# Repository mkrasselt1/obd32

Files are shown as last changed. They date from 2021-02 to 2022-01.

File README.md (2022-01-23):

# obd32
The goal of this project is to create a esp32 based pcb and software to
catch and submit automotive data from obd2 ports of supported vehicles 
to a given (list of ) endpoints(s). 

Anyone is free to join our goal to make the hardware reliable and affordable.

current plan conatins the featureset of:

    - esp32 based microprocessor
    - direct canbus via tranciever chip MCP2562-e
    - db9 for obd2 connection
    - wifi connection to hotsport or
    - onboard switchable usb port for lte-wifi-router 
    - ~~bluetooth connection compatible with elm327ds~~
    - micro sd card slot for configuration, logging and cache
    - ota updates via github releases
    - build in webfrontend
    - low power sleep mode (canbus activity and battery voltage)
    - gps for location and altitude sync
    - communication protocolls: https-post, websocket, mqtt

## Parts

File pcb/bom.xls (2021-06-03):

Comment | Designator | Quantity | Footprint | Datasheet
4K7 | R1, R2 | 2 | R_0603_1608Metric | ~
10K | R3, R23, R24 | 3 | R_0402_1005Metric | ~
64.9R | R4, R5 | 2 | R_0402_1005Metric | ~
4.99R | R6 | 1 | R_0402_1005Metric | ~
22.1K | R7 | 1 | R_0402_1005Metric | ~
47.5K | R8 | 1 | R_0402_1005Metric | ~
1K | R9 | 1 | R_0402_1005Metric | ~
100K | R10, R21 | 2 | R_0402_1005Metric | ~
27K | R11 | 1 | R_0402_1005Metric | ~
200K | R12 | 1 | R_0402_1005Metric | ~
22K | R13 | 1 | R_0402_1005Metric | ~
5.1K | R14, R15 | 2 | R_0402_1005Metric | ~
27R | R16, R19 | 2 | R_0402_1005Metric | ~
120R | R17 | 1 | R_0402_1005Metric | ~
10R | R18 | 1 | R_0402_1005Metric | ~
24.9K | R22 | 1 | R_0402_1005Metric | ~
100nF | C1, C3 | 2 | C_0805_2012Metric | ~
1uF | C2, C10 | 2 | C_0402_1005Metric | ~
10uF | C4, C6 | 2 | C_0805_2012Metric | ~
22uF | C5, C12, C13, C25 | 4 | C_0805_2012Metric | ~
10uF 20V | C7 | 1 | C_0805_2012Metric | ~
220nF 20V | C8 | 1 | C_0402_1005Metric | ~
0.1uF | C9, C11, C16, C18, C19, C20, C21 | 7 | C_0402_1005Metric | ~
10nF | C14 | 1 | C_0402_1005Metric | ~
0.47uF | C15 | 1 | C_0402_1005Metric | ~
100nF | C17, C22 | 2 | C_0402_1005Metric | ~
LED | D1 | 1 | LED_0402_1005Metric red | ~
LED | D2 | 1 | LED_0402_1005Metric green | ~
LED | D3 | 1 | LED_0402_1005Metric blue | ~
SM6T18A | D4 | 1 | D_SMB | https://www.digikey.com/en/products/detail/stmicroelectronics/SM6T18A/1039077
D_Schottky | D5, D8 | 2 | D_SMA | https://www.digikey.com/en/products/detail/vishay-general-semiconductor-diodes-division/SSB43L-M3-5BT/4872661
SP0503BAHT | D6 | 1 | SOT-143 | https://www.digikey.com/en/products/detail/littelfuse-inc/SP0503BAHT/485122
D_Zener | D7 | 1 | D_0201_0603Metric | https://www.digikey.com/en/products/detail/diodes-incorporated/GDZ6V0LP3-7/3075699
Polyfuse | F1 | 1 | Fuse_1812_4532Metric | https://www.digikey.com/en/products/detail/littelfuse-inc/1812L150-16DR/3305611
67329-8040 | J1 | 1 | Molex 67329-8040 | https://www.digikey.com/en/products/detail/molex/0673298040/13572467
USB_C_Receptacle_USB2.0 | J2 | 1 | USB_C_Receptacle JAE DX07S016JA1 | https://www.digikey.com/en/products/detail/jae-electronics/DX07S016JA1R1500/11585731
Micro_SD_Card | J6 | 1 | microSD_HC_Hirose_DM3AT-SF-PEJM5 | https://www.digikey.com/en/products/detail/hirose-electric-co-ltd/DM3AT-SF-PEJM5/2533565
U.FL-R-SMT-101 | J7 | 1 | U.FL-R-SMT-101 | https://www.digikey.com/en/products/detail/hirose-electric-co-ltd/U-FL-R-SMT-1-01/3978494
3.3uH 4A 16mR | L2 | 1 | TDK_SPM5030 | https://www.digikey.com/en/products/detail/tdk-corporation/SPM5030T-3R3M/9555054
BC817 | Q1, Q2 | 2 | Generic BC817 SOT-23
SW_Push | SW1, SW2, SW3 | 3 | Switch B3U-3000P-B | https://www.digikey.com/en/products/detail/omron-electronics-inc-emc-div/B3U-3000P-B/1811779
FTDI FT231XQ | U1 | 1 | FT231XQ QFN20 | https://www.digikey.com/en/products/detail/ftdi-future-technology-devices-international-ltd/FT231XQ-T/3749470
ESP32-WROOM-32 | U2 | 1 | ESP32-WROOM-32U (16MB) | https://www.digikey.com/en/products/detail/espressif-systems/ESP32-WROOM-32U-16MB/9381721
AZ1117C-3.3 | U3 | 1 | AZ1117R-3.3TRE1 | https://www.digikey.com/en/products/detail/diodes-incorporated/AZ1117R-3-3TRE1/5306009
LMR33640DDDA | U4 | 1 | LMR33640DDDAR | https://www.digikey.com/en/products/detail/texas-instruments/LMR33640DDDAR/11308833
MCP2562FD-E-MF or MCP2562FD-H-MF | U7 | 1 | Package_DFN_QFN:DFN-8-1EP_3x3mm_P0.65mm_EP1.55x2.4mm | https://www.digikey.com/en/products/detail/microchip-technology/MCP2562FD-E-MF/4842806
SiP32431DR3 | U8 | 1 | Package_TO_SOT_SMD:SOT-363_SC-70-6 | https://www.digikey.com/en/products/detail/vishay-siliconix/SIP32431DR3-T1GE3/2643559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
v Below may be left unpopulated if not available v
Ublox MAX-M8W | U9 | 1 | RF_GPS:ublox_MAX | https://www.digikey.com/en/products/detail/u-blox/MAX-M8W-0/6150637
ICM-20689 | U5 | 1 | ICM-20689 | https://www.digikey.com/en/products/detail/tdk-invensense/ICM-20689/5872869
BMP388 | U6 | 1 | BMP388 | https://www.digikey.com/en/products/detail/bosch-sensortec/BMP388/8322638

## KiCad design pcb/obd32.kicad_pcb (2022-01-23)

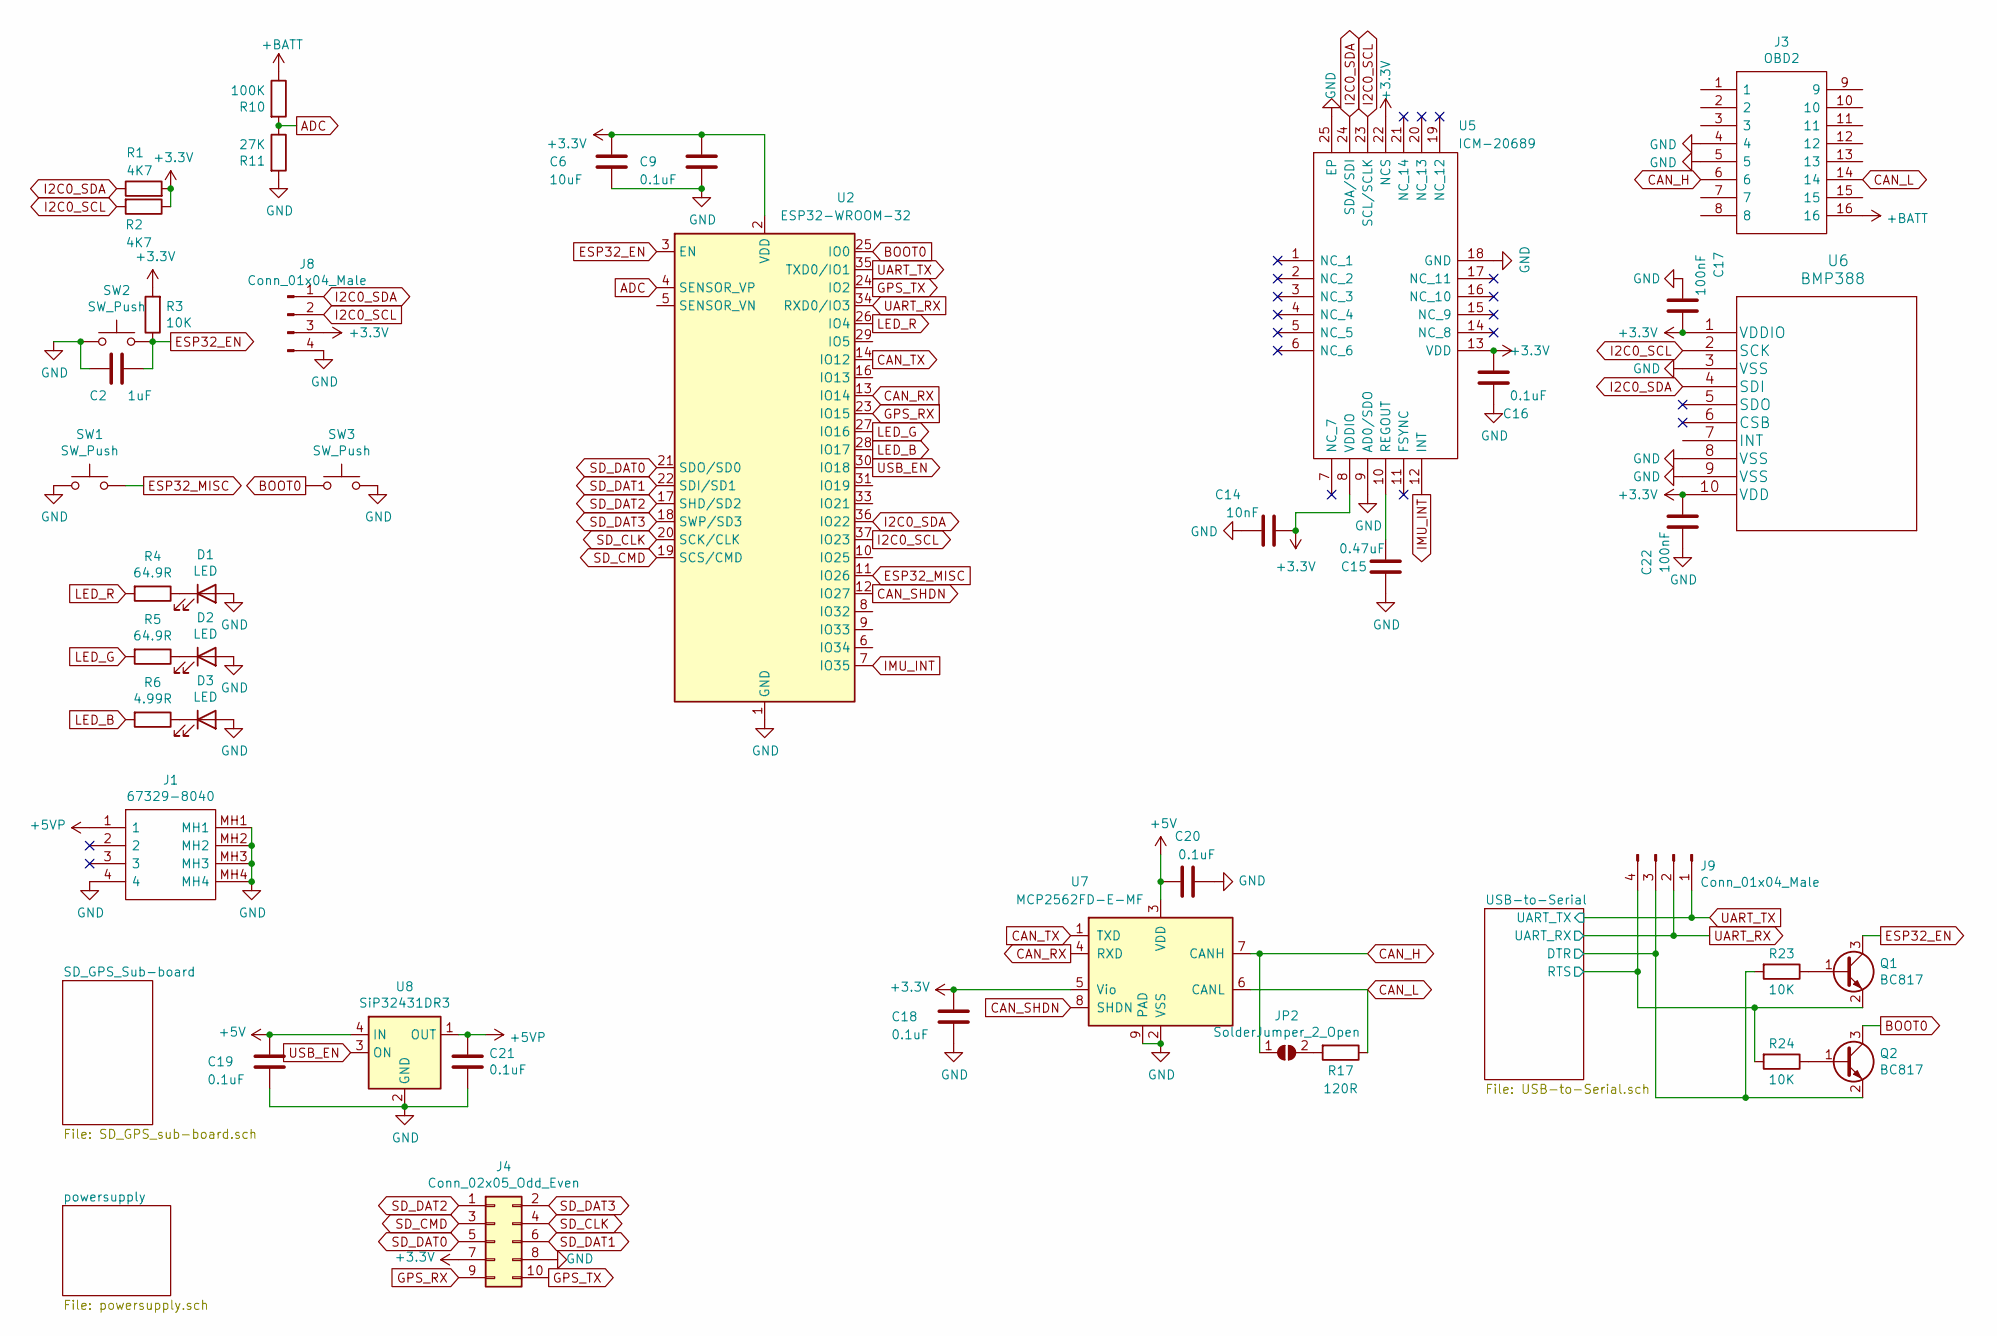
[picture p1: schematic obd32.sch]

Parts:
C2: 1uF; C_0402_1005Metric
C6: 10uF; C_0805_2012Metric
C9, C16, C18, C19, C20, C21: 0.1uF; C_0402_1005Metric
C14: 10nF; C_0402_1005Metric
C15: 0.47uF; C_0402_1005Metric
C17, C22: 100nF; C_0402_1005Metric
D1, D2, D3: LED; LED_0402_1005Metric
J1: 67329-8040; 673298040; Manufacturer_Part_Number 67329-8040; Mouser Part Number 538-67329-8040
J3: OBD2; Manufacturer_Part_Number OBD2
J4: Conn_02x05_Odd_Even; PinSocket_2x05_P2.54mm_Vertical
J8, J9: Conn_01x04_Male; PinHeader_1x04_P2.54mm_Vertical
JP2: SolderJumper_2_Open; SolderJumper-2_P1.3mm_Open_RoundedPad1.0x1.5mm
Q1, Q2: BC817; SOT-23
R1, R2: 4K7; R_0603_1608Metric
R3, R23, R24: 10K; R_0402_1005Metric
R4, R5: 64.9R; R_0402_1005Metric
R6: 4.99R; R_0402_1005Metric
R10: 100K; R_0402_1005Metric
R11: 27K; R_0402_1005Metric
R17: 120R; R_0402_1005Metric
SW1, SW2, SW3: SW_Push; SW_SPST_B3U-3000P-B
U2: ESP32-WROOM-32; ESP32-WROOM-32U
U5: ICM-20689; QFN50P400X400X95-25N-D; Manufacturer_Part_Number ICM-20689; Mouser Part Number 410-ICM-20689
U6: BMP388
U7: MCP2562FD-E-MF; DFN-8-1EP_3x3mm_P0.65mm_EP1.55x2.4mm
U8: SiP32431DR3; SOT-363_SC-70-6

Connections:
+3V3: C6.1, C9.1, C14.2, C16.2, C17.2, C18.2, C22.2, J4.7, J8.3, R1.2, R2.1, R3.2, U2.2 (VDD), U5.8 (VDDIO), U5.13 (VDD), U5.22 (NCS), U6.1 (VDDIO), U6.10 (VDD), U7.5 (Vio); also elsewhere on the board
+5V: C19.1, C20.1, U7.3 (VDD), U8.4 (IN); also elsewhere on the board
+5VP: C21.1, J1.1, U8.1 (OUT)
+BATT: J3.16, R10.1; also elsewhere on the board
/USB-to-Serial/DTR: J9.3, Q2.2 (E), R23.2; also elsewhere on the board
/USB-to-Serial/RTS: J9.4, Q1.2 (E), R24.2; also elsewhere on the board
ADC: R10.2, R11.1, U2.4 (SENSOR_VP)
BOOT0: Q2.3 (C), SW3.1, U2.25 (IO0)
CAN_H: J3.6, JP2.1 (A), U7.7 (CANH)
CAN_L: J3.14, R17.1, U7.6 (CANL)
CAN_RX: U2.13 (IO14), U7.4 (RXD)
CAN_SHDN: U2.12 (IO27), U7.8 (SHDN)
CAN_TX: U2.14 (IO12), U7.1 (TXD)
ESP32_EN: C2.2, Q1.3 (C), R3.1, SW2.2, U2.3 (EN)
ESP32_MISC: SW1.2, U2.11 (IO26)
GND: C2.1, C6.2, C9.2, C14.1, C15.1, C16.1, C17.1, C18.1, C19.2, C20.2, C21.2, C22.1, D1.2 (A), D2.2 (A), D3.2 (A), J1.4, J1.MH1, J1.MH2, J1.MH3, J1.MH4, J3.4, J3.5, J4.8, J8.4, R11.2, SW1.1, SW2.1, SW3.2, U2.1 (GND), U2.15 (GND), U2.38 (GND), U2.39 (GND), U5.9 (AD0/SDO), U5.18 (GND), U5.25 (EP), U6.3 (VSS), U6.8 (VSS), U6.9 (VSS), U7.2 (VSS), U7.9 (PAD), U8.2 (GND), U8.5 (GND); also elsewhere on the board
GPS_RX: J4.9, U2.23 (IO15)
GPS_TX: J4.10, U2.24 (IO2)
I2C0_SCL: J8.2, R2.2, U2.37 (IO23), U5.23 (SCL/SCLK), U6.2 (SCK)
I2C0_SDA: J8.1, R1.1, U2.36 (IO22), U5.24 (SDA/SDI), U6.4 (SDI)
IMU_INT: U2.7 (IO35), U5.12 (INT)
LED_B: R6.2, U2.28 (IO17)
LED_G: R5.2, U2.27 (IO16)
LED_R: R4.2, U2.26 (IO4)
unnamed: C15.2, U5.10 (REGOUT)
unnamed: D1.1 (K), R4.1
unnamed: D2.1 (K), R5.1
unnamed: D3.1 (K), R6.1
unnamed: JP2.2 (B), R17.2
unnamed: Q1.1 (B), R23.1
unnamed: Q2.1 (B), R24.1
SD_CLK: J4.4, U2.20 (SCK/CLK)
SD_CMD: J4.3, U2.19 (SCS/CMD)
SD_DAT0: J4.5, U2.21 (SDO/SD0)
SD_DAT1: J4.6, U2.22 (SDI/SD1)
SD_DAT2: J4.1, U2.17 (SHD/SD2)
SD_DAT3: J4.2, U2.18 (SWP/SD3)
UART_RX: J9.2, U2.34 (RXD0/IO3); also elsewhere on the board
UART_TX: J9.1, U2.35 (TXD0/IO1); also elsewhere on the board
USB_EN: U2.30 (IO18), U8.3 (ON)

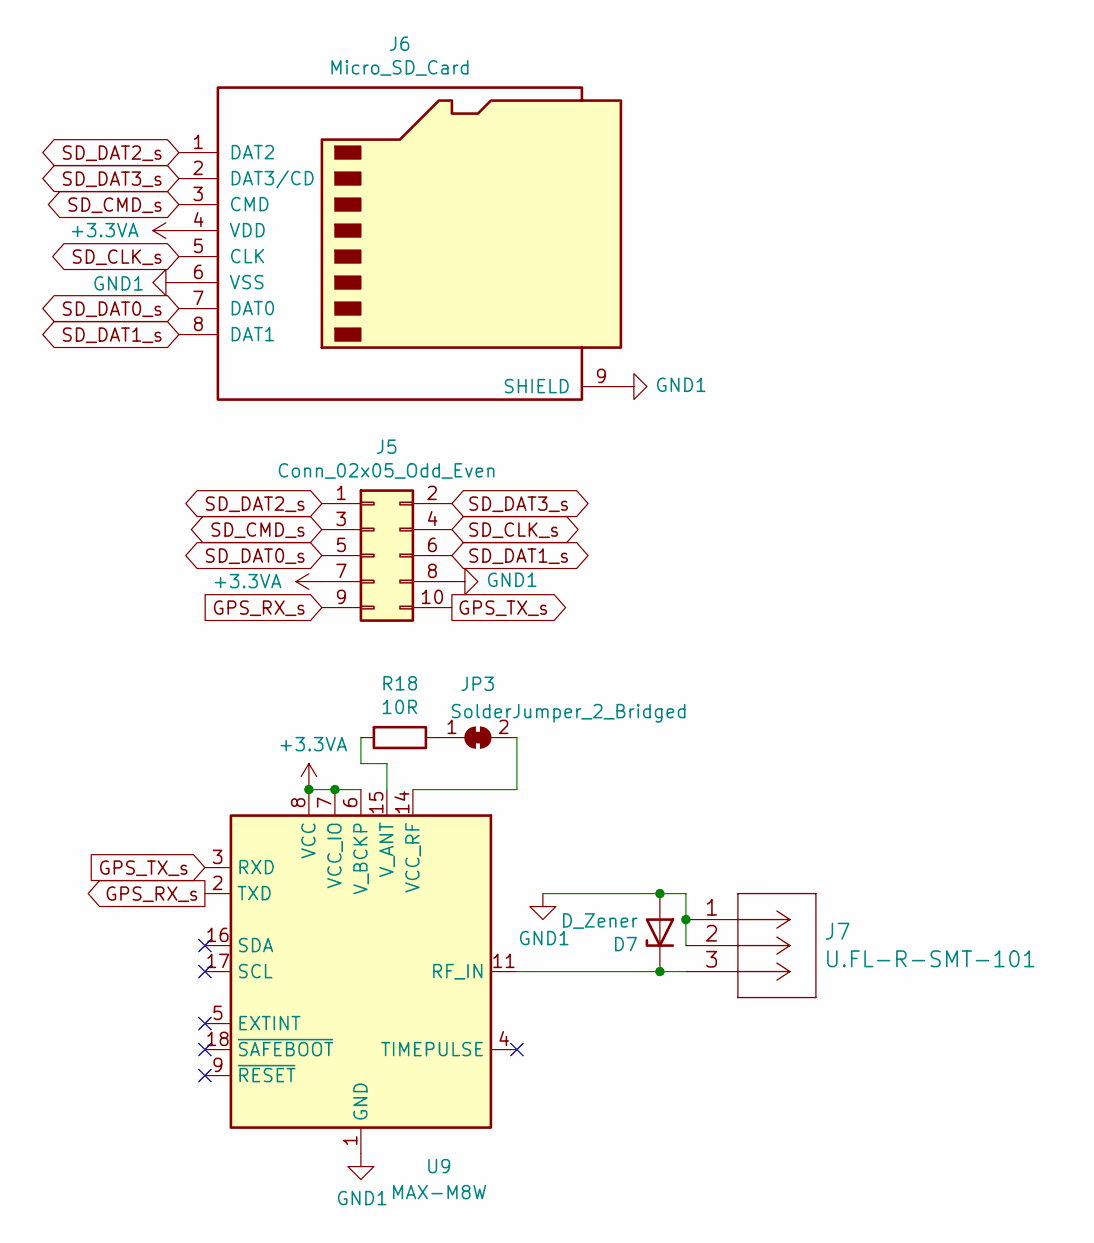
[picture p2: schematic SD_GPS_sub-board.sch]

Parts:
D7: D_Zener; D_0201_0603Metric
J5: Conn_02x05_Odd_Even; PinHeader_2x05_P2.54mm_Vertical
J6: Micro_SD_Card; microSD_HC_Hirose_DM3AT-SF-PEJM5
J7: U.FL-R-SMT-101
JP3: SolderJumper_2_Bridged; SolderJumper-2_P1.3mm_Bridged_RoundedPad1.0x1.5mm
R18: 10R; R_0402_1005Metric
U9: MAX-M8W; ublox_MAX

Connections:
+3.3VA: J5.7, J6.4 (VDD), U9.6 (V_BCKP), U9.7 (VCC_IO), U9.8 (VCC)
GND1: D7.2 (A), J5.8, J6.6 (VSS), J6.9 (SHIELD), J7.1 (GND), J7.2 (GND), U9.1 (GND), U9.10 (GND), U9.12 (GND)
GPS_RX_s: J5.9, U9.2 (TXD)
GPS_TX_s: J5.10, U9.3 (RXD)
unnamed: D7.1 (K), J7.3 (SIG), U9.11 (RF_IN)
unnamed: JP3.1 (A), R18.1
unnamed: JP3.2 (B), U9.14 (VCC_RF)
unnamed: R18.2, U9.15 (V_ANT)
SD_CLK_s: J5.4, J6.5 (CLK)
SD_CMD_s: J5.3, J6.3 (CMD)
SD_DAT0_s: J5.5, J6.7 (DAT0)
SD_DAT1_s: J5.6, J6.8 (DAT1)
SD_DAT2_s: J5.1, J6.1 (DAT2)
SD_DAT3_s: J5.2, J6.2 (DAT3/CD)

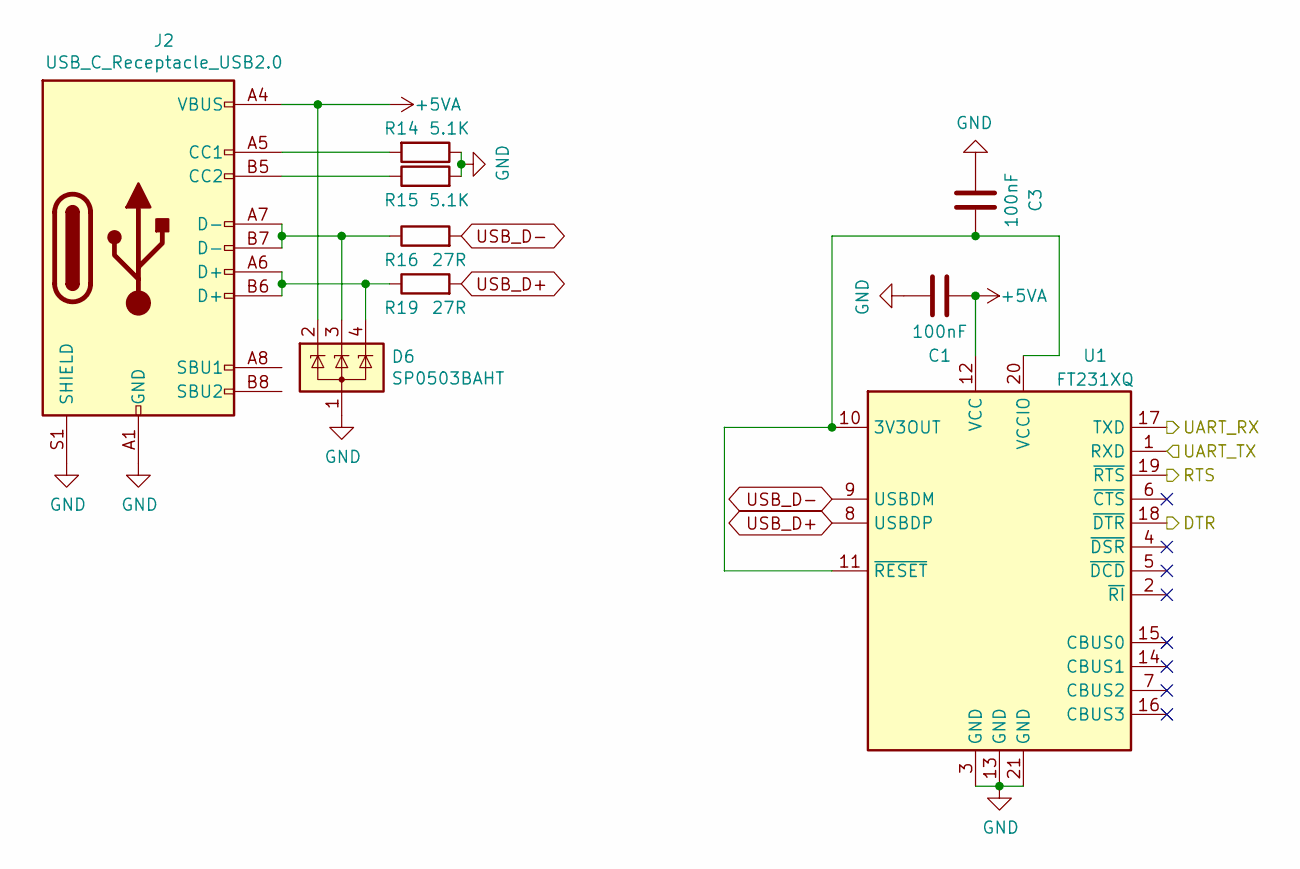
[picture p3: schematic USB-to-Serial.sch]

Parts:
C1, C3: 100nF; C_0805_2012Metric
D6: SP0503BAHT; SOT-143
J2: USB_C_Receptacle_USB2.0; USB_C_Receptacle_JAE_DX07S016JA1
R14, R15: 5.1K; R_0402_1005Metric
R16, R19: 27R; R_0402_1005Metric
U1: FT231XQ; QFN-20-1EP_4x4mm_P0.5mm_EP2.5x2.5mm

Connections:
+5VA: C1.2, D6.2 (K), J2.A4 (VBUS), J2.A9 (VBUS), J2.B4 (VBUS), J2.B9 (VBUS), U1.12 (VCC); also elsewhere on the board
/USB-to-Serial/DTR: U1.18 (~DTR); also elsewhere on the board
/USB-to-Serial/RTS: U1.19 (~RTS); also elsewhere on the board
GND: C1.1, C3.2, D6.1 (A), J2.A1 (GND), J2.A12 (GND), J2.B1 (GND), J2.B12 (GND), J2.S1 (SHIELD), R14.1, R15.2, U1.3 (GND), U1.13 (GND), U1.21 (GND); also elsewhere on the board
unnamed: C3.1, U1.10 (3V3OUT), U1.11 (~RESET), U1.20 (VCCIO)
unnamed: D6.3 (K), J2.A7 (D-), J2.B7 (D-), R16.1
unnamed: D6.4 (K), J2.A6 (D+), J2.B6 (D+), R19.1
unnamed: J2.A5 (CC1), R14.2
unnamed: J2.B5 (CC2), R15.1
UART_RX: U1.17 (TXD); also elsewhere on the board
UART_TX: U1.1 (RXD); also elsewhere on the board
USB_D+: R19.2, U1.8 (USBDP)
USB_D-: R16.2, U1.9 (USBDM)

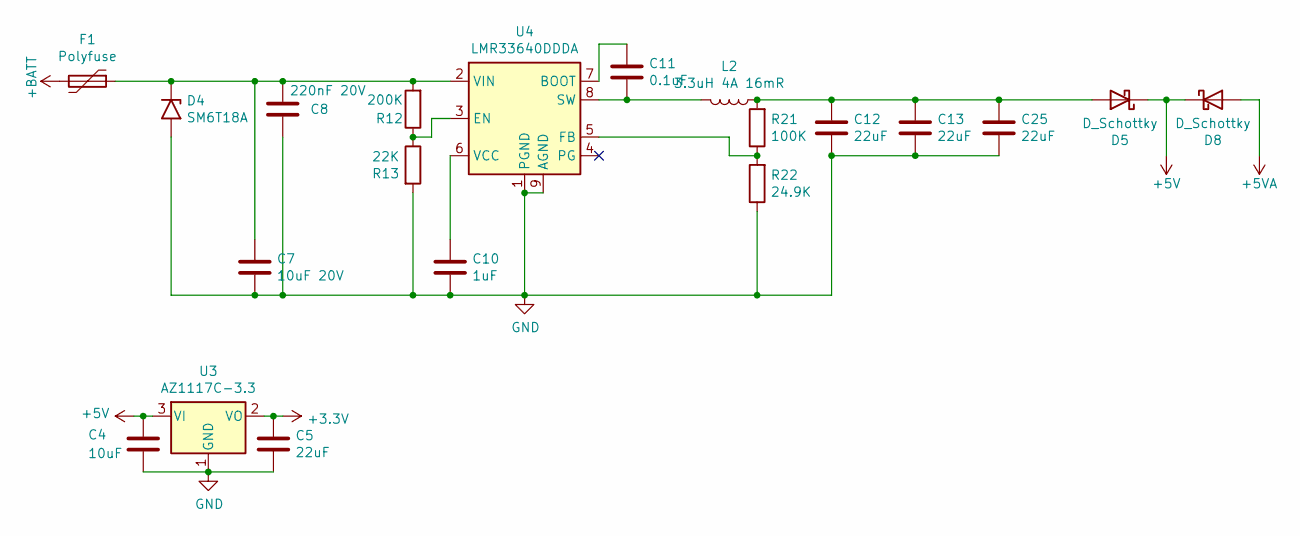
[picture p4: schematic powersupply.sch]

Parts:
C4: 10uF; C_0805_2012Metric
C5, C12, C13, C25: 22uF; C_0805_2012Metric
C7: 10uF 20V; C_0805_2012Metric
C8: 220nF 20V; C_0402_1005Metric
C10: 1uF; C_0402_1005Metric
C11: 0.1uF; C_0402_1005Metric
D4: SM6T18A; D_SMB
D5, D8: D_Schottky; D_SMA
F1: Polyfuse; Fuse_1812_4532Metric_Castellated
L2: 3.3uH 4A 16mR; TDK_SPM5030
R12: 200K; R_0402_1005Metric
R13: 22K; R_0402_1005Metric
R21: 100K; R_0402_1005Metric
R22: 24.9K; R_0402_1005Metric
U3: AZ1117C-3.3; SOT-89-3
U4: LMR33640DDDA; Texas_HSOP-8-1EP_3.9x4.9mm_P1.27mm_ThermalVias

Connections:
+3V3: C5.1, U3.2 (VO); also elsewhere on the board
+5V: C4.1, D5.1 (K), D8.1 (K), U3.3 (VI); also elsewhere on the board
+5VA: D8.2 (A); also elsewhere on the board
+BATT: F1.2; also elsewhere on the board
GND: C4.2, C5.2, C7.2, C8.2, C10.2, C12.2, C13.2, C25.2, D4.2 (A2), R13.2, R22.1, U3.1 (GND), U4.1 (PGND), U4.9 (AGND); also elsewhere on the board
unnamed: C7.1, C8.1, D4.1 (A1), F1.1, R12.2, U4.2 (VIN)
unnamed: C10.1, U4.6 (VCC)
unnamed: C11.1, U4.7 (BOOT)
unnamed: C11.2, L2.2, U4.8 (SW)
unnamed: C12.1, C13.1, C25.1, D5.2 (A), L2.1, R21.2
unnamed: R12.1, R13.1, U4.3 (EN)
unnamed: R21.1, R22.2, U4.5 (FB)

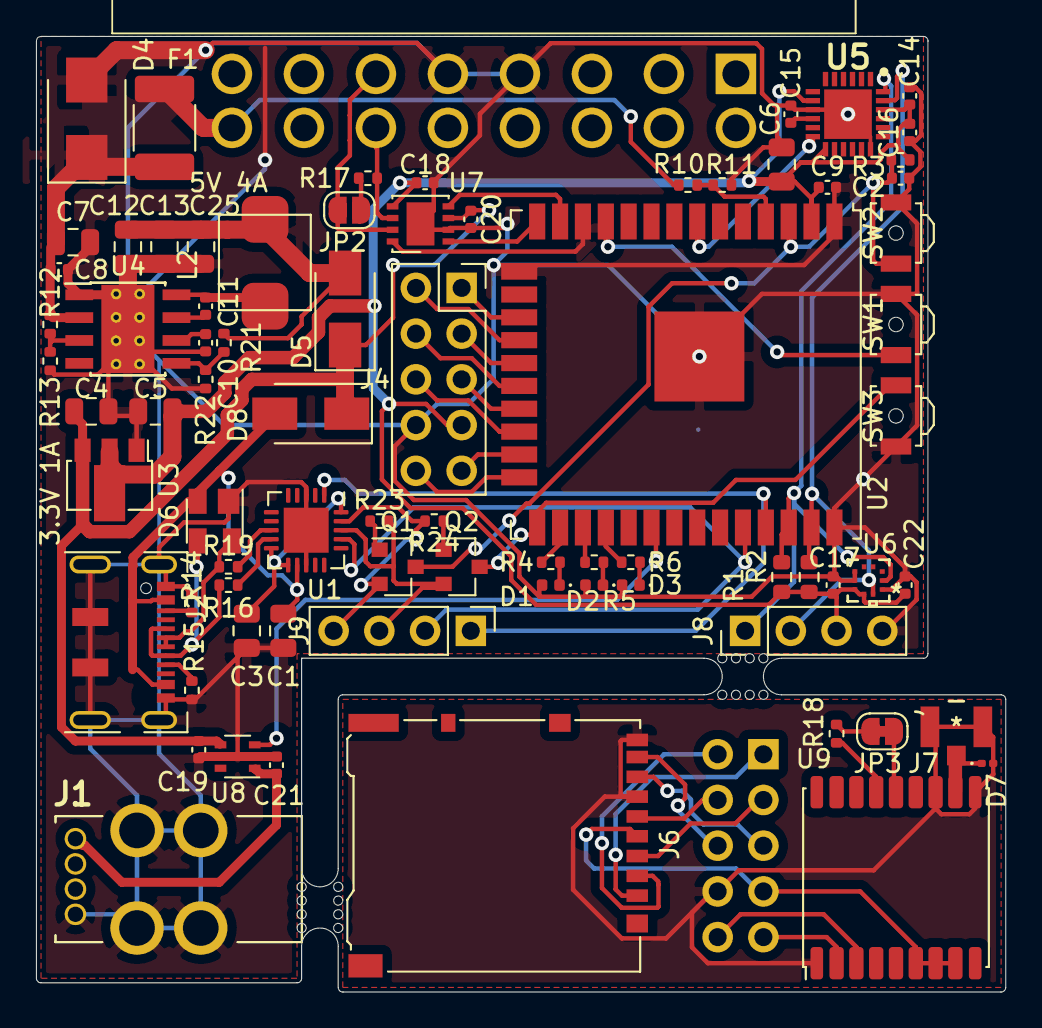
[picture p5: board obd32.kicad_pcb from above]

Board: 2 copper layers, 53.8 x 53.1 mm, 78 parts (1 on the bottom side), 69 nets.

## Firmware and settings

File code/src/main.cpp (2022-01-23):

#include <Arduino.h>
#include <Update.h>
#include "FS.h"
#include "SPIFFS.h"
#include "Wifi.h"
#include <WiFiClient.h>
#include <ESPmDNS.h>
#include <AsyncTCP.h>
#include <ESPAsyncWebServer.h>
#include "pins.h"

const char *sta_ssid = "obd32";
const char *sta_password = "obd32";
const char *host = "obd32";

unsigned long previousMillis = 0; // will store last time LED was updated
const long interval = 150;        // interval at which to blink (milliseconds)
int ledState = 0;                 // ledState used to set the LED
bool leddirection = false;           // direction of leds
bool shouldReboot = false;        //flag to use from web update to reboot the ESP

// Create AsyncWebServer object on port 80
AsyncWebServer server(80);
AsyncWebSocket ws("/ws");
AsyncEventSource events("/events"); // event source (Server-Sent events)

void notifyClients()
{
    ws.textAll(String(ledState));
}

void handleWebSocketMessage(void *arg, uint8_t *data, size_t len)
{
    AwsFrameInfo *info = (AwsFrameInfo *)arg;
    if (info->final && info->index == 0 && info->len == len && info->opcode == WS_TEXT)
    {
        data[len] = 0;
        if (strcmp((char *)data, "toggle") == 0)
        {
            ledState = !ledState;
            notifyClients();
        }
    }
}

void onEvent(AsyncWebSocket *server, AsyncWebSocketClient *client, AwsEventType type,
             void *arg, uint8_t *data, size_t len)
{
    switch (type)
    {
    case WS_EVT_CONNECT:
        Serial.printf("WebSocket client #%u connected from %s\n", client->id(), client->remoteIP().toString().c_str());
        break;
    case WS_EVT_DISCONNECT:
        Serial.printf("WebSocket client #%u disconnected\n", client->id());
        break;
    case WS_EVT_DATA:
        handleWebSocketMessage(arg, data, len);
        break;
    case WS_EVT_PONG:
    case WS_EVT_ERROR:
        break;
    }
}

// Replaces placeholder with LED state value
String processor(const String &var)
{
    Serial.println(var);
    if (var == "STATE")
    {
        Serial.print(ledState);
        return String(ledState);
    }
    return String();
}

void onRequest(AsyncWebServerRequest *request)
{
    //Handle Unknown Request
    request->send(404);
}

void setup()
{
    Serial.begin(115200);

    pinMode(GPIO_BTN1, INPUT_PULLUP);
    pinMode(GPIO_USB_EN, OUTPUT);
    pinMode(GPIO_LED_R, OUTPUT);
    pinMode(GPIO_LED_G, OUTPUT);
    pinMode(GPIO_LED_B, OUTPUT);

    // Initialize SPIFFS
    if (!SPIFFS.begin(true))
    {
        Serial.println("An Error has occurred while mounting SPIFFS");
        return;
    }

    WiFi.begin(sta_ssid, sta_password);
    Serial.println("Connecting to WiFi");
    while (WiFi.status() != WL_CONNECTED)
    {
        delay(500);
        Serial.print(".");
    }
    Serial.println("WiFi connected");
    Serial.println("IP address: ");
    Serial.println(WiFi.localIP());

    /*use mdns for host name resolution*/
    if (!MDNS.begin(host))
    { //http://esp32.local
        Serial.println("Error setting up MDNS responder!");
        while (1)
        {
            delay(1000);
        }
    }

    Serial.println("mDNS responder started");

    // Route for root / web page
    server.serveStatic("/", SPIFFS, "/")
        .setDefaultFile("index.html")
        .setAuthentication("obd32", "obd32");

    /*handling uploading firmware file */

    // upload a file to /upload
    server.on(
        "/update", HTTP_POST, [](AsyncWebServerRequest *request)
        {
            shouldReboot = !Update.hasError();
            AsyncWebServerResponse *response = request->beginResponse(200, "text/plain", shouldReboot ? "OK" : "FAIL");
            response->addHeader("Connection", "close");
            request->send(response);
        },
        [](AsyncWebServerRequest *request, String filename, size_t index, uint8_t *data, size_t len, bool final)
        {
            if (!index)
            {
                Serial.printf("Update Start: %s\n", filename.c_str());
                //Update.runAsync(true);
                if (filename == "spiffs.bin")
                {
                    // size_t fsSize = ((size_t)&_FS_end - (size_t)&_FS_start);
                    size_t fsSize = SPIFFS.totalBytes();
                    SPIFFS.end();
                    SPIFFS.begin();
                    if (!Update.begin(fsSize, U_SPIFFS)) //start with max available size
                    {
                        Update.printError(Serial);
                    }
                }
                else if (filename == "firmware.bin")
                {
                    if (!Update.begin((ESP.getFreeSketchSpace() - 0x1000) & 0xFFFFF000))
                    {
                        Update.printError(Serial);
                    }
                }
                else
                {
                    Serial.println("Filename not matching");
                }
            }
            if (!Update.hasError())
            {
                if (Update.write(data, len) != len)
                {
                    Update.printError(Serial);
                }
            }
            if (final)
            {
                if (Update.end(true))
                {
                    Serial.printf("Update Success: %uB\n", index + len);
                }
                else
                {
                    Update.printError(Serial);
                }
            }
        });
    server.begin();
}

void loop()
{
    ws.cleanupClients();
    delay(1);
    if (shouldReboot)
    {
        Serial.println("Rebooting...");
        delay(100);
        ESP.restart();
    }
    static char temp[128];
    sprintf(temp, "Seconds since boot: %u", millis() / 1000);
    events.send(temp, "time"); //send event "time"

    //loop to blink without delay
    unsigned long currentMillis = millis();
    if (currentMillis - previousMillis >= interval)
    {
        // save the last time you blinked the LED
        previousMillis = currentMillis;
        if(leddirection){
            ledState--;
        }else{
            ledState++;
        }
        
        digitalWrite(GPIO_LED_R, false);
        digitalWrite(GPIO_LED_G, false);
        digitalWrite(GPIO_LED_B, false);
        switch (ledState)
        {
        case 1:
            digitalWrite(GPIO_LED_R, true);
            break;
        case 2:
            digitalWrite(GPIO_LED_G, true);
            break;
        case 3:
            digitalWrite(GPIO_LED_B, true);
            break;
        default:
            leddirection=!leddirection;
            if(leddirection){
                ledState=4;
            }else{
                ledState=0;
            }
        }
        // set the LED with the ledState of the variable:

        Serial.print("Set LED to: ");
        Serial.println(ledState);
    }
}

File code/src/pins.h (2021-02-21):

// vv GPIO number vv
#define GPIO_UART_RX 3		// UART0
#define GPIO_UART_TX 1		// UART0
#define GPIO_GPS_RX 15		// UART2
#define GPIO_GPS_TX 2		// UART2
#define GPIO_CAN_RX 14		// CAN
#define GPIO_CAN_TX 12		// CAN
#define GPIO_I2C0_SDA 22	// I2C
#define GPIO_I2C0_SCL 23	// I2C
#define GPIO_ADC 36 		// ADC1_CH0
#define GPIO_BTN1 26		// ESP32_MISC
#define GPIO_USB_EN 18
#define GPIO_LED_R 4
#define GPIO_LED_G 16
#define GPIO_LED_B 17
#define GPIO_CS_SDCARD 4    // Chip Select SD Card

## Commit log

2020-11-02 Add: Readme Project Description \n Add: Basic PCB Design
    [Control.brd, Control.sch]
2020-11-09 FIX: Simple ODB2 Scanner
    [main.cpp]
2020-11-14 first prototype of decoder
2020-11-28 working prototype of ISO-TP- and car decoder
2020-11-29 1st draft
    [obd32.kicad_pcb, obd32.sch]
2020-11-30 Maybe version of board
    [obd32.kicad_pcb, obd32.sch]
2020-12-02 Board: Add USB-C and CP2102 UART converter
    [obd32.kicad_pcb, obd32.sch]
2020-12-02 Board: Add cuttable solder jumper to allow disconnection from 12V rail
    [obd32.kicad_pcb, obd32.sch]
2020-12-03 Board: replace pressure sensor with more common bmp280
    [obd32.kicad_pcb, obd32.sch]
2020-12-07 Add header for pin mapping; put stuff into main
2020-12-07 Board: some refinement; Add button BOOT0
    [obd32.kicad_pcb, obd32.sch]
2020-12-27 PIO: use hopefulle fitting board
2021-02-21 PCB: Move components from bottom to top side of board. Move SD-card slot to sub board. Add SAM-M8N GPS-receiver
    [SD_GPS_sub-board.sch, obd32.kicad_pcb, obd32.sch]
2021-02-25 BMP280 was replaced with BMP388, adjust code accordingly
    [main.cpp]
2021-02-26 Add: Seperate Threads for GPS and Backend
2021-03-07 Board: use different USB-C Receptable
    [SD_GPS_sub-board.sch, obd32.kicad_pcb, obd32.sch]
2021-03-07 Board: add Gerber files
    [obd32-B_Cu.gbr, obd32-B_Mask.gbr, obd32-B_Paste.gbr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]
2021-06-03 Board: Adjustments
    [SD_GPS_sub-board.sch, USB-to-Serial.sch, bom.xls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]
2022-01-23 Moved prototype code to main.old; Add: OTA Update Capabilitys; Add: WEB Interface with events and websocket server Add: OTA Web Interface
    [obd32.kicad_pcb]

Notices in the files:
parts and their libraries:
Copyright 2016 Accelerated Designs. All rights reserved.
